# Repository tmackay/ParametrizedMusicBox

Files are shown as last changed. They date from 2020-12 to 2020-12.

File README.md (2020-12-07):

# Parametrized Music Box - Print in Place
Available as a Thingiverse Customizer [Print in Place Music Box](https://www.thingiverse.com/thing:4672175).
Also on [MyMinifactory](https://www.myminifactory.com/object/3d-print-143523).
Musical calculations remixed from [Parametric Music Box](https://www.thingiverse.com/thing:53235).

[See it in action](https://youtu.be/H7jwQiykk-s),
[and in closer](https://youtu.be/OX5avwUwEng)

I'd strongly suggest ABS or something with good fatigue resistance for this one. Not only does PLA not have a good "plink", the fingers won't survive long from being repeatedly plucked. (see below)

Print at 0.2mm layer height (check in preview that the 1-layer gaps are preserved when slicing). Somewhat sensitive to bed level and overextrusion so dial your printer in with a tolerance gauge.

Don't get your hopes up, I was somewhat disappointed by the acoustic properties of PLA but it's a nice little toy none the less.

Post-printing, free up the gears by turning the knob clockwise (due to the direction of the herringbone gears - less likely to break). I use a 5/16" socket to get a bit more leverage on the knob. The key is controlled force and repetitive small motions until it breaks free.

Next use a straight-edged razor to delaminate the two ring gears. Just wedge it in enough to hear a small crack all the way around. Turning the gears will do the rest.

Some of the "fingers" will free up on their own, the others can be helped gently with the razor. A sliver of an aluminium can can be a useful scraper to get inbetween.

The version with the 1-layer gap between fingers doesn't sound too hot (the fingers rub on each other) but requires no support. I made another with a 3-layer gap which can use a layer of support material (high overhang angle so it doesn't mess with the gears). I was tempted to build support into the model but decided this was the job of the slicer. Only the finger tips need to be supported as the rest can bridge, so strategic use of support blockers will make it easier to remove (40mm cube -25mm in x).

This model is really just a gimmick, but I can see something like this being incorporated into a design which provides a high RPM input and a sound board. Something like a little wind turbine. Otherwise, if it had a bit more weight, you could hold it by the knob and twirl it.

UPDATE: The first critical design flaw has surfaced (apart from needing a little post-processing finesse). The fingers will suffer fatigue failure after a few hours of continuous use. I am currently experimenting with strain relief structures but suspect this may be a hard limitation of PLA. Alternatives may exist by incorporating other materials eg. bamboo inserts or altering the design to use rigid moving parts such as little hammers sprung by an elastic band. Angling the fingers might also help by not plucking them so aggressively.

UPDATE2: Apologies for the very rough code - this was a quick weekend idea that I didn't expect to take off so quickly. There are a lot of unused parameters left over from copy and pasting from different models. I'll try and tidy that up as soon as I can.

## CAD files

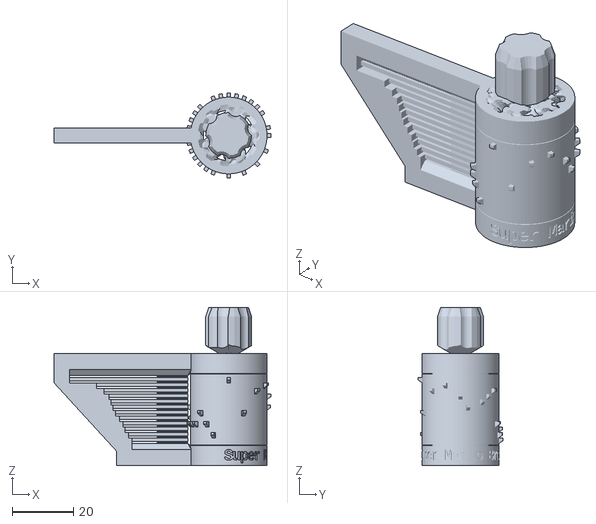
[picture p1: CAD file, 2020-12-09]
FullyPrintableParametricMusicBox.stl
70.8 x 27.6 x 51.6

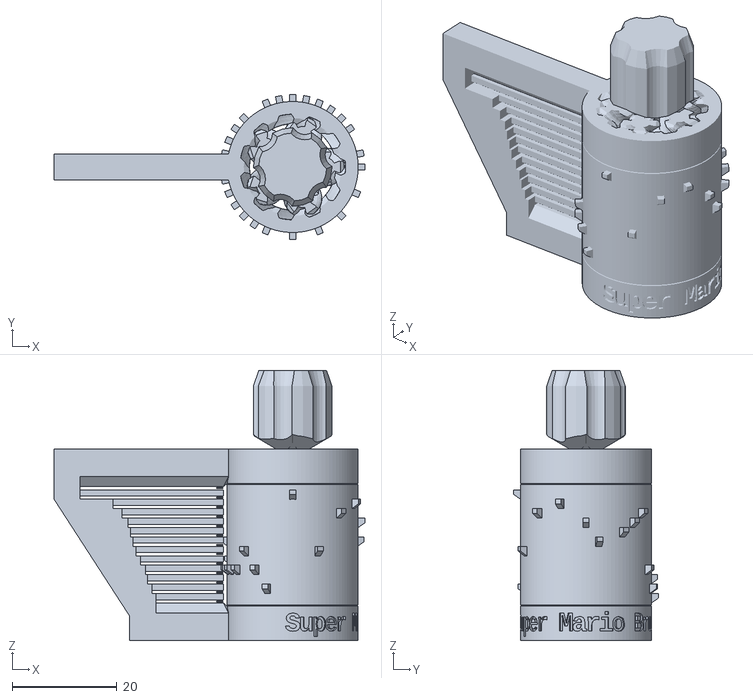
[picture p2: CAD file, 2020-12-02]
FullyPrintableParametricMusicBox-support.stl
59.4 x 27.6 x 51.6

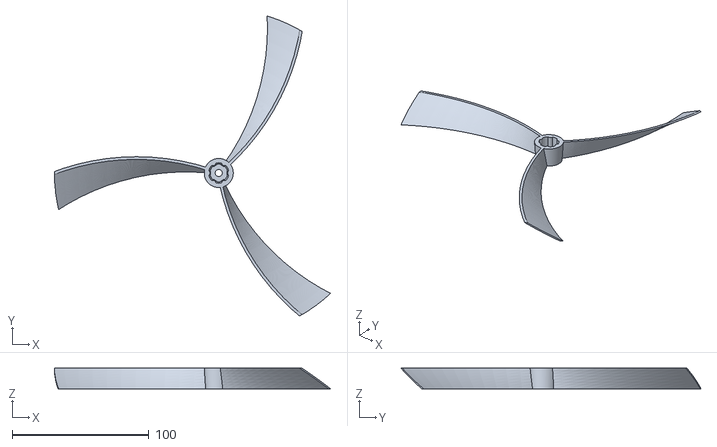
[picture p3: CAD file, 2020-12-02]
Turbine_generator.stl
201.6 x 219.1 x 15.0

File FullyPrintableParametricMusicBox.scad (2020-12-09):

/*
 * Print in Place Parametric Music Box
 * Copyright (C) 2020 Troy Mackay
 *
 * This program is free software; you can redistribute it and/or modify
 * it under the terms of the GNU General Public License as published by
 * the Free Software Foundation; either version 2 of the License, or
 * (at your option) any later version.
 *
 * This program is distributed in the hope that it will be useful,
 * but WITHOUT ANY WARRANTY; without even the implied warranty of
 * MERCHANTABILITY or FITNESS FOR A PARTICULAR PURPOSE.  See the
 * GNU General Public License for more details.
 *
 * The latest version can be found here:
 * https://github.com/tmackay/ParametrizedMusicBox
 *
 * Musical geometry forked from https://github.com/wizard23/ParametrizedMusicBox
 * Fully Printed Parametric Music Box With Exchangeable Song-Cylinders
 * Copyright (C) 2013  Philipp Tiefenbacher <wizards23@gmail.com>
 *
 */

include <SCCPv1.scad>

// this text will be put on top of the music cylinder
MusicCylinderName="Super Mario Bros";
// What font do you want to use for the text?
MusicCylinderNameFont="Liberation Mono:style=Bold";
// how large should the font be
MusicCylinderNameFontSize = 8;
// how deep should the name be carved in?
MusicCylinderNameDepth=0.5;
// the width of all the walls in the design.
wall=2.5;
// how many vibrating teeth should there be? (also number of available notes) You can use the output of the generator for this field: http://www.wizards23.net/projects/musicbox/musicbox.html
pinNrX = 12;
// what should the notes on the teeth be? Each note is encoded by 3 characters: note (C,D,E,F,G,A,B), then the accidental (#, b or blank), and then the a one digit octave. You can use the output of the generator for this field: http://www.wizards23.net/projects/musicbox/musicbox.html
teethNotes="G 0E 1G 1A 1Bb1B 1C 2D 2E 2F 2G 2A 2";
// how many time slots should there be, including the starting position? (If you make this much higher you should also increase musicCylinderTeeth) You can use the output of the generator for this field: http://www.wizards23.net/projects/musicbox/musicbox.html
pinNrY = 32;
// the actual song. each time slot has pinNrX characters. X marks a pin everything else means no pin. You can use the output of the generator for this field: http://www.wizards23.net/projects/musicbox/musicbox.html
pins="ooooooooXoooooooooooXoooooooooooXoooooooooXoooooooooooooXoooooooooooooXoooooooooooooXoooooooooooooooooooooooooooooXoooooooooooooooooooXooooooooooooooooooooooXoooooooooooooooooooooooooXoooooooooooooXooooooooooooooooooooooXooooooooooXooooooooooXoooooooooooooooooXoooooooooooooXooooooooooooXoooooooooXooooooooooooXoooooooooooooooooooooXoooooooooXooooooooooooXoooooooooXoooooo";
// the number of teeth on the music cylinder
musicCylinderTeeth = 24;
// Constants section
// the density of PLA (or whatever plastic you are using) in kg/m3 ((( scientiffically derived by me by taking the average of the density values I could find onthe net scaled a little bit to take into account that the print is not super dense (0.7 * (1210 + 1430)/2) )))
ro_PLA = 924; 
// elasticity module of the plastic you are using in N/m2 ((( derived by this formula I hope I got the unit conversion right 1.6*   1000000 *(2.5+7.8)/2 )))
E_PLA = 8240000; 
// the gamma factor for the geometry of the teeth (extruded rectangle), use this to tune it if you have a finite state modell of the printed teeth :) taken from http://de.wikipedia.org/wiki/Durchschlagende_Zunge#Berechnung_der_Tonh.C3.B6he
gammaTooth = 1.875; 
// the frequency of C0 (can be used for tuning if you dont have a clue about the material properties of you printing material :)
baseFrequC0 = 8.1758;
// (TODO) the angle of the teeth relative to the cylinder (0 would be normal to cylinder, should be some small (<10) positive angle)
noteAlpha = 0;
// diametral pitch of the gear (if you make it smaller the teeth become bigger (the addendum becomes bigger) I tink of it as teeth per unit :)
diametral_pitch = 0.96;
// the height of all the gears
gearH=6.6;
// direction that crank hast to be turned it to play the song (has a bug: music is played backwards in clockwise mode so better leave it counter clockwise)
crankDirection = 0; // [1:Clockwise, 0:CounterClockwise]
// used for clean CSG operations
epsilonCSG = 0.1;
teethH = 1.2;
// how far the musical pins protrure from the cylinder
pinH = 1;
// gap between piano fingers and music cylinder
pteethMinD = 0.8;
// vertical gaps between piano fingers
teethGap = 0.6;
// thickness of musical pins on cylinder
pinD=1.2;
// Thickness of teeth frame
teethHolderW=5;
// Length of generated tooth tip support structure in model
generateSupport=10;

// Gearbox Section
// TODO:Overall scale (to avoid small numbers, internal faces or non-manifold edges)
scl = 1;
// Number of planet gears in gearbox
planets = 5; //[3:1:21]
// Layer height (for ring horizontal split)
layer_h_ = 0.2; //[0:0.01:1]
// Bearing height
bearing_h_ = 1;  //[0:0.01:5]
// Number of teeth in planet gears
pt = [4, 5, 5, 4];
// For additional gear ratios we can add or subtract extra teeth (in multiples of planets) from rings but the profile will be further from ideal
of = [0, 0, 0, 0];
// number of teeth to twist across
nt = [1, 1, 1, 1];
// Sun gear multiplier
sgm = 1; //[1:1:5]
// Shaft diameter
shaft_d_ = 0; //[0:0.1:25]
// Outside Gear depth ratio
depth_ratio=0.25; //[0:0.05:1]
// Inside Gear depth ratio
depth_ratio2=0.5; //[0:0.05:1]
// Gear clearance
tol_=0.2; //[0:0.01:0.5]
// pressure angle
P=30; //[30:60]
// Chamfer exposed gears, top - watch fingers
ChamferGearsTop = 0;				// [1:No, 0.5:Yes, 0:Half]
// Chamfer exposed gears, bottom - help with elephant's foot/tolerance
ChamferGearsBottom = 0;				// [1:No, 0.5:Yes, 0:Half]
//Include a knob
Knob = 1;				// [1:Yes , 0:No]
//Diameter of the knob, in mm
KnobDiameter_ = 15.0;			//[10:0.5:100]
//Thickness of knob, including the stem, in mm:
KnobTotalHeight_ = 15;			//[10:thin,15:normal,30:thick, 40:very thick]
//Number of points on the knob
FingerPoints = 6;   			//[3,4,5,6,7,8,9,10]
//Diameter of finger holes
FingerHoleDiameter_ = 5; //[5:0.5:50]
TaperFingerPoints = true;			// true
// Simplified model without gears
draft = 1; // [0:No, 1:Yes]
// Outer teeth
outer_t = [5,7];

// Tolerances for geometry connections.
AT_=1/64;
// Curve resolution settings, minimum angle
$fa = 5/1;
// Curve resolution settings, minimum size
$fs = 1/1;
// Curve resolution settings, number of segments
$fn=96;

// common calculated variables
musicH=pinNrX*(1.2+teethGap);
// Height of planetary layers (layer_h will be subtracted from gears>0)
gearH2 = (musicH+3*(teethGap-layer_h_)+teethHolderW-teethH-bearing_h_-layer_h_-teethHolderW+teethH)/2; // TODO: layer_h dependency?
gh_ = [gearH+bearing_h_-layer_h_,gearH2,gearH2,gearH+bearing_h_]*1;
modules = len(gh_);
core_h = scl*addl(gh_,len(gh_));
bearing_h = scl*bearing_h_;
gh = scl*gh_;
layer_h = scl*layer_h_;
tol = scl*tol_;
AT=AT_*scl;
ST=AT*2;
TT=AT/2;

//// Derived Music stuff
circular_pitch = 180/diametral_pitch;
addendum = 1/diametral_pitch;
pinStepX = musicH/pinNrX;
pinStepY = 360/pinNrY;

teethW = pinStepX-teethGap;
maxTeethL=TeethLen(0); // convention index 0 is lowest note
///////////////////////

musicCylinderR = (musicCylinderTeeth/diametral_pitch)/2;
noteExtend = teethHolderW+maxTeethL + pteethMinD; 
maxMusicAddendum = 1.5*max(addendum, pinH);

// noteExtend in alpha angle projected to y and x-axis
noteExtendY = sin(noteAlpha)*noteExtend;
noteExtendX = cos(noteAlpha)*noteExtend;
noteBeta = asin(noteExtendY/musicCylinderR);

// musicCylinderR to intersection with noteExtend
musicCylinderRX = cos(noteBeta)*musicCylinderR;

negXEnd = -(noteExtendX+musicCylinderRX);

echo("Testing NoteToFrequ, expected freq is 440");
echo(NoteToFrequ(9, 4, 0));

//// SPECFIC functions
function TeethLen(x) = 
	1000*LengthOfTooth(NoteToFrequ(LetterToNoteIndex(teethNotes[x*3]), 
			LetterToDigit(teethNotes[x*3+2]),
			AccidentalToNoteShift(teethNotes[x*3+1])),
			teethH/1000, E_PLA, ro_PLA);

//// PLATONIC functions
// http://de.wikipedia.org/wiki/Durchschlagende_Zunge#Berechnung_der_Tonh.C3.B6he
// f [Hz]
// h m
// E N/m2
// ro kg/m3
function LengthOfTooth(f, h, E, ro) = sqrt((gammaTooth*gammaTooth*h/(4*PI*f))*sqrt(E/(3*ro)));

function NoteToFrequ(note, octave, modification) = baseFrequC0*pow(2, octave)*pow(2, (note+modification)/12);

function AccidentalToNoteShift(l) = l=="#"?1:l=="b"?-1:l==" "?0:INVALID_ACCIDENTAL_CHECK_teethNotes();

// allow B and H
// todo allow big and small letters
function LetterToNoteIndex(l) = l=="C"?0:l=="D"?2:l=="E"?4:l=="F"?5:l=="G"?7:l=="A"?9:l=="H"?11:l=="B"?11:INVALID_NOTE_CHECK_teethNotes();

function LetterToDigit(l) = l=="0"?0:l=="1"?1:l=="2"?2:l=="3"?3:l=="4"?4:l=="5"?5:l=="6"?6:l=="7"?7:l=="8"?8:l=="9"?9:INVALID_DIGIT_IN_OCTAVE_CHECK_teethNotes();
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

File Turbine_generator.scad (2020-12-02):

// Overall scale (to avoid small numbers, internal faces or non-manifold edges)
scl = 1;
// Layer height (for ring horizontal split)
layer_h_ = 0.2; //[0:0.01:1]
// Gear clearance
tol_=0.2; //[0:0.01:0.5]
// Tolerances for geometry connections.
AT_=1/64;
// Curve resolution settings, minimum angle
$fa = 5/1;
// Curve resolution settings, minimum size
$fs = 1/1;
// Curve resolution settings, number of segments
$fn=96;
//Include a knob
Knob = 1;				// [1:Yes , 0:No]
//Diameter of the knob, in mm
KnobDiameter = 15.0;			//[10:0.5:100]
//Thickness of knob, including the stem, in mm:
KnobTotalHeight = 15;			//[10:thin,15:normal,30:thick, 40:very thick]
//Number of points on the knob
FingerPoints = 6;   			//[3,4,5,6,7,8,9,10]
//Diameter of finger holes
FingerHoleDiameter = 5; //[5:0.5:50]
TaperFingerPoints = true;			// true

//layer_h = scl*layer_h_;
tol = scl*tol_;
AT=AT_*scl;
ST=AT*2;
TT=AT/2;

module knob(){
    // Knob by Hank Cowdog 2 Feb 2015, somewhat modified
    //Diameter of the shaft thru-bolt, in mm 
    ShaftDiameter = 0;
    ShaftEasingPercentage = 0/100.0;  // 10% is plenty
    NutFlatWidth = 1.75 * ShaftDiameter;
    NutHeight =     0.87 * ShaftDiameter;
    SineOfSixtyDegrees = 0.86602540378/1.0;
    NutPointWidth = NutFlatWidth /SineOfSixtyDegrees;
    EasedShaftDiameter = ShaftDiameter * (1.0+ShaftEasingPercentage);
    // center gears and knob

        if(Knob)
            intersection(){
                translate([0,0,KnobTotalHeight])mirror([0,0,1])difference(){
                    // The whole knob
                    cylinder(h=KnobTotalHeight+TT, r=KnobDiameter/2, $fn=24);
                    // each finger point
                    for (i = [0 : FingerPoints-1]){
                        rotate( i * 360 / FingerPoints, [0, 0, 1])
                        translate([(KnobDiameter *.6), 0, -1])
                        union() {
                            // remove the vertical part of the finger hole 
                            cylinder(h=KnobTotalHeight+2, r=FingerHoleDiameter/2, $fn=24);
                            // taper the sides of the finger points 
                            if(TaperFingerPoints) {
                                rotate_extrude(convexity = 10, $fn=24)
                                    translate([FingerHoleDiameter/2.0, 0, 0])
                                    polygon( points=scl*[[2,-3],[-1,6],[-1,-3]] );
                            }
                        }
                    }
                    // Drill the shaft
                    translate([0,0,KnobTotalHeight+1])scale([1,1,-1])union(){
                        //The thru-shaft
                        cylinder(h=KnobTotalHeight+2, r=EasedShaftDiameter/2., $fn=24);
                    }
                    // taper the ends of the points
                    if(TaperFingerPoints) {
                        rotate_extrude(convexity = 10, $fn=24)
                        translate([KnobDiameter/2, 0, 0])
                        polygon( points=scl*[[-2,-3],[1,6],[1,-3]] );
                    }
                }
                // Transition knob to gear. Cutout overhanging teeth at angle
                //gear2D(dt[modules-1],cp[modules-1]*PI/180,P,depth_ratio2,depth_ratio,tol,KnobTotalHeight,AT);
        }
    }

//Denise Lee, 12March2017

/*
//In RC hobby propeller nomenclature
//Propeller diameter X distance travelled per revolution (in silly inches!)
inch_mm = 25.4;
prop_dia = 6; //propeller diameter
prop_dist = 3.8; //propeller distance travelled
blade_radius = prop_dia*inch_mm/2;
pitch_angle = atan(prop_dist*inch_mm/blade_radius);
*/



blade_radius = 120;
pitch_angle = 30; //Converting pitch to twist angle for linear extrude

blade_arch = blade_radius/11; // Curvature of blades, selected straight edge or use ARC module 
apply_curvature = 1; //1 Curve blades, 0 for straight edge

echo("Blade Radius", blade_radius);
echo("Pitch Angle", pitch_angle);
echo("Blade Arch", blade_arch); 

printer_layer_height = 0.2; //for preview (F5) x20, set this to 0.1 for rendering for export STL(F6)!!!
blade_thickness = 2; //thickness of blade
turbine_height = 15;
num_blades = 3;
rotation_dir = 1; //CCW = -1, CW = 1

pi = 3.14159265359;
blade_cirf = 2*pi*blade_radius;
twist_angle = 360*turbine_height/(blade_cirf*tan(pitch_angle));

echo("Twist Angle: ", twist_angle);

slicing = turbine_height / printer_layer_height; //equal printing slicing height

percent_offset = 50; //Percent of turbine height with blades at blade radius
//offset_slicing must be greater or equal slicing
offset_slicing = round(slicing*(1/((100-percent_offset)/100)));  

echo("Percent Offset:", percent_offset);

layer_h = turbine_height/offset_slicing;

bot_r = blade_radius; //Bottom blade radius
//bot_r = 7.5;
top_r= blade_radius;

delta_r = top_r - bot_r;

stem_top_r = 7+2.6;
stem_bot_r = 8+2.6;

shaft_fit_r = 2.6; //Your connecting motor pin to turbine 
shaft_fit_l = turbine_height;

translate([0,0,turbine_height])mirror([0,0,1])mirror([1,0,0])
difference() {
union() {

intersection() {



//Blades
linear_extrude(height=turbine_height, center = false, convexity = 10, twist = twist_angle*rotation_dir, slices = slicing)
  for(i=[0:num_blades-1])
    rotate((360*i)/num_blades)
      translate([0,-blade_thickness/2]) { 
        if(apply_curvature != 1) { square([blade_radius, blade_thickness]); }
        else {
            if(rotation_dir == -1) {
                mirror([0,1,0])
                arc(blade_radius, blade_thickness, blade_arch); 
            }
            else {arc(blade_radius, blade_thickness, blade_arch);}
      }}
 

  
//Non-linear extrusion    

//Curve convex
//y = 1 - 1/exp(x)
exp_pow = 3;
end_point = 1 - 1/exp(exp_pow*1); 

union() {
for (i=[0:offset_slicing-1]){
    if (i < slicing) { 
        offset_r = delta_r*((1-1/exp(exp_pow*(i/slicing)))/end_point); //Normalised N
        offset_r_increment = delta_r*((1-1/exp(exp_pow*((i+1)/slicing)))/end_point); //Normalised N+1  
        translate([0,0,i*layer_h])
        cylinder(layer_h, bot_r + offset_r, bot_r + offset_r_increment, center=false, $fn=100);
    }
    else {
        translate([0,0,i*layer_h])
        cylinder(layer_h, top_r, top_r, center=false, $fn=100);    
    }    

}}

/*
//Curve concave    
//y = base^x - 1
//base = exp(1);
base = 3;
end_point = pow(base,1)-1;

union() {
for (i=[0:offset_slicing-1]){
    if (i < slicing) {
        offset_r = delta_r*((pow(base,i/slicing)-1)/end_point); //Normalised N 
        offset_r_increment = delta_r*((pow(base,(i+1)/slicing)-1)/end_point);  //Normalised N+1    
        translate([0,0,i*layer_h])
        cylinder(layer_h, bot_r + offset_r, bot_r + offset_r_increment, center=false, $fn=100);
    }
    else {
        translate([0,0,i*layer_h])
        cylinder(layer_h, top_r, top_r, center=false, $fn=100);    
    }
    //echo("Layer: ", i);    
}}*/

}

cylinder( turbine_height, stem_bot_r, stem_top_r,center=false, $fn=100); //Centre stem

}
translate([0,0,-2])knob();
cylinder( shaft_fit_l, shaft_fit_r, shaft_fit_r, center=false, $fn=100); } //Push fit cutout




//length and breath of inner arc
module arc(length, width, arch_height){
    //r = (l^2 + 4*b^2)/8*b 
    radius = (pow(length,2) + 4*pow(arch_height,2))/(8*arch_height);
    echo(radius);
    translate([length/2,0,0])
    difference() {
    difference() {
        translate([0,-radius+arch_height,0])
            difference() {
                circle(r=radius+width,$fn=100);
                circle(r=(radius),$fn=100);
            }
        
        translate([-(radius+width),-(radius+width)*2,0,])
            square([(radius+width)*2,(radius+width)*2]);
    }
    union() {
        translate([-length,-arch_height]) 
            square([length/2,arch_height*2]);
        translate([length/2,-arch_height])     
            square([length/2,arch_height*2]);
    }}    
}

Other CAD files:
SCCPv1.scad

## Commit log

2020-11-29 stripped back
    [FullyPrintableParametricMusicBox.scad]
2020-11-29 rough in
    [FullyPrintableParametricMusicBox.scad]
2020-11-29 trim and smooth
    [FullyPrintableParametricMusicBox.scad]
2020-11-29 first draft
    [FullyPrintableParametricMusicBox.scad]
2020-11-29 mario tune
    [FullyPrintableParametricMusicBox.scad]
2020-11-29 correct timeslots and start
    [FullyPrintableParametricMusicBox.scad]
2020-11-29 scale was upside down
    [FullyPrintableParametricMusicBox.scad]
2020-11-30 added gap between teeth and turbine
    (use support with steep overhang)
    [FullyPrintableParametricMusicBox.scad, Turbine_generator.scad, Turbine_generator.stl]
2020-12-02 strain relief and geometry tweaks
    [FullyPrintableParametricMusicBox.scad]
2020-12-02 generate support
    [FullyPrintableParametricMusicBox.scad]
2020-12-07 parameter tidy up
    [FullyPrintableParametricMusicBox.scad]
2020-12-07 parameter comments
    [FullyPrintableParametricMusicBox.scad]
2020-12-09 tweaks to reduce fatigue, drop down an octave
    [FullyPrintableParametricMusicBox.scad, FullyPrintableParametricMusicBox.stl]
